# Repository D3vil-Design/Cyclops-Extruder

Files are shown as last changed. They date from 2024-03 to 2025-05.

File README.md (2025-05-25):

# Cyclops_Extruder ( Discontinued )

22nd september 2024 update:

Added 1.9.1 body , and tensioner arm for better print 
also added extra spacer that help in some cases where the gear are not tight fit and slides around 
Special thanks to "intensivecarebear80" ( discord User ) for the help in refining the designs and introducing the PTFE holder.

----------

The D3vil Designs "Cyclops" extruder was specifically engineered to address issues
associated with the stock Creality K1 / K1 Max extruder. Not only is the Cyclops a seamless
direct drop-in upgrade, but it also draws on proven technology from the Orbiter 2 project.
This integration enables the Cyclops to inherit superior functionality and performance
improvements, including but not limited to:
- Retraction speeds up to 120 mm/s
- Acceleration up to 3000 mm/s^2
- A powerful LDO Motor
- Large precise drive wheels for increased filament grip
- Improved and direct filament path to meet your needs (PLA, PETG, ASA, ABS, TPU, etc.)
This document serves as a reference guide. For optimal results, users must exercise care
and attentiveness during the assembly and installation processes. Neglecting to adhere
to the provided instructions may lead to suboptimal performance.
Note: This extruder requires root access to your printer.cfg in klipper.

Get full support at cuclops support channel on D3vil design discord 
Discord.gg/D3vil-Design

and feel free to join our Patreon for support, special offers , discounts and giveaways.
patreon.com/D3vilDesign

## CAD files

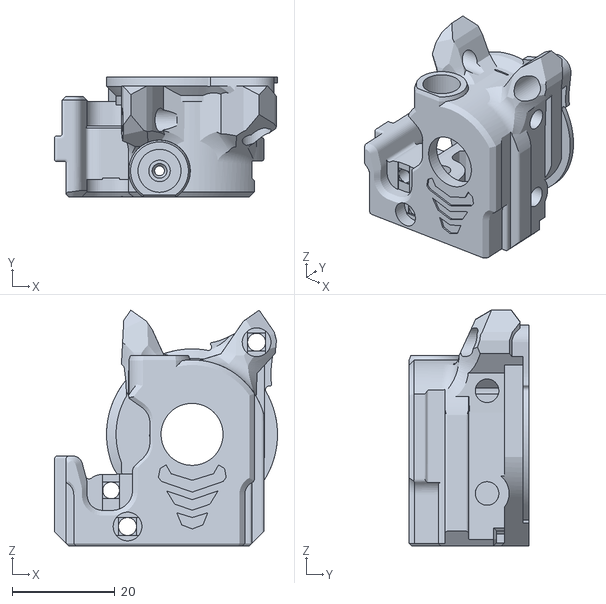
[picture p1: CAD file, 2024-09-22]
Models/Cyclops beta 1.9.1 Latest Sep24.stl
43.4 x 23.4 x 45.9

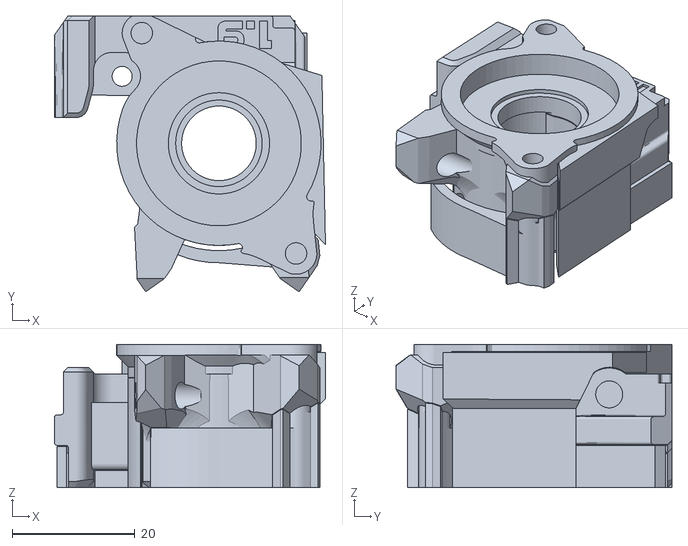
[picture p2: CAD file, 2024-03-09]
Models/PreSupported/Cyclops_v1.9_Supported.stl
44.1 x 44.9 x 23.4

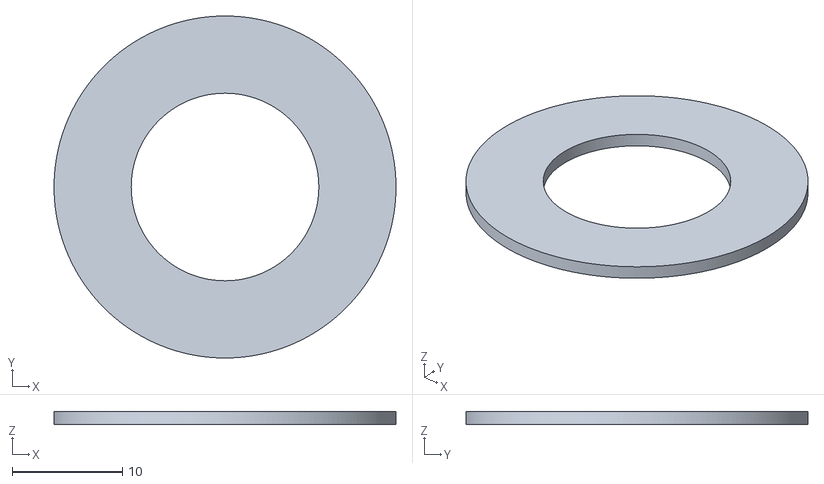
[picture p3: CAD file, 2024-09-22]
Models/Cyclops spacer Sep24.stl
31.0 x 31.0 x 1.20

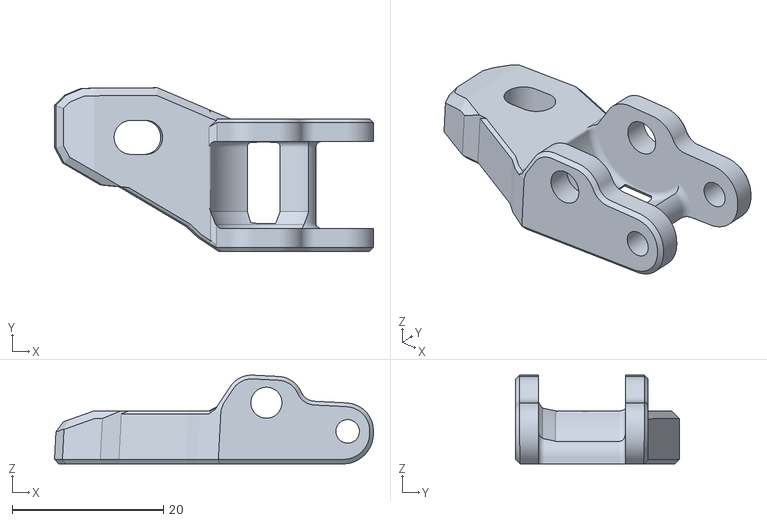
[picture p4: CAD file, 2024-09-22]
Models/Cyclops 1.9.1 Tensioner upgraded Sep24 (1).stl
42.2 x 21.6 x 11.7

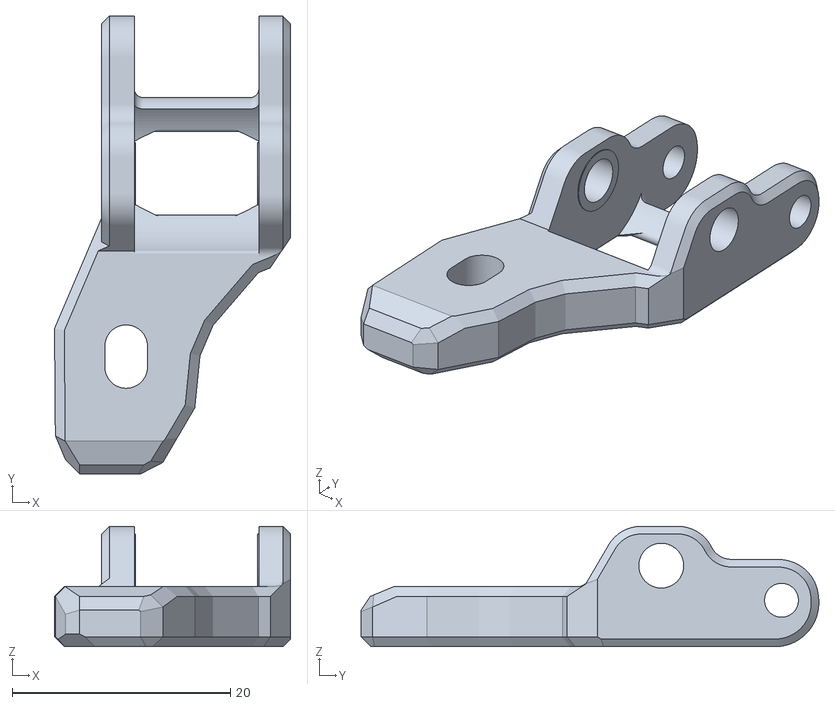
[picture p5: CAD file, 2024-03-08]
Models/Cyclops_Tensioner_1.9.stl
21.6 x 41.9 x 11.0

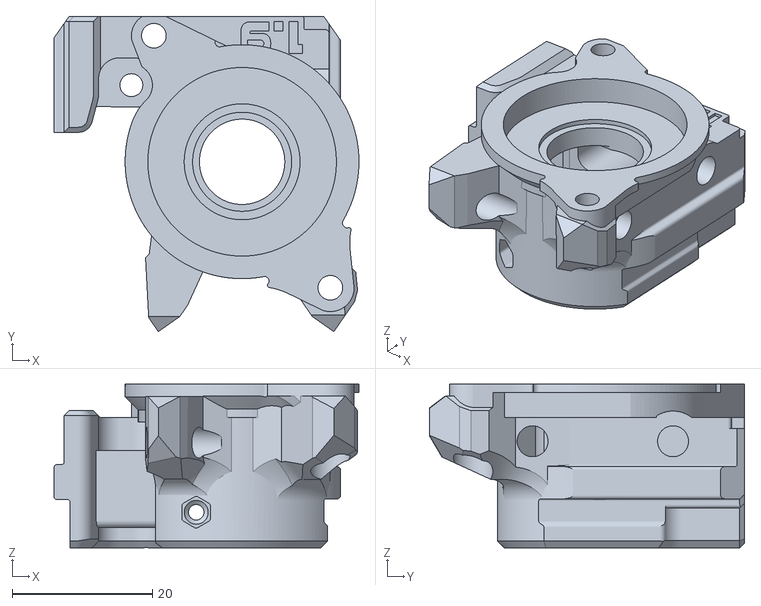
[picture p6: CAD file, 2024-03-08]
Models/Cyclops_Body_1.9.stl
43.4 x 44.9 x 23.3

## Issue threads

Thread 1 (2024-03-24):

Errors in the manual Guide/Cyclops Manual v1.5.pdf

NAPCAL, 2024-03-24:
Page 3
MR128 bearing (ID 8.0mm x OD 12.0mm x **3.5mm**)
The kit provides an MR128 bearing (ID 8.0mm, OD 12.0mm x **2.5mm**).
You can find both types, but most **2.5mm** versions will be open without shielding.

Pages 16-18
These show a drive gear with a grub/set screw hole, but the one provided in the kit is a type with no grub/set screw hole; this may confuse some builders.

DerrickDarrell, 2024-03-24:
We'll look into this, thanks

epicteammate, 2024-04-04:
To add to this post, perhaps this is just limited to myself:

Page 29
The "!" was not necessary for my printer, it caused everything to go backwards when I tested it loading/unloading and extruding/retracting. I haven't fully assembled it yet cause my PTFE tubing got lost in transit but that was my testing while hooked up and running the commands via Guppy screen.

mfraser, 2024-10-05:
Page 26. The PTFE tube is not required if you already have or are planning on using the Unicorn extruder.

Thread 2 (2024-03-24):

K1 wipe cycle; back of motor hits the back of the printer.

NAPCAL, 2024-03-24:
During the wipe cycle, the motor hits the back of the frame and rubs across while wiping.
This doesn't happen during bed mesh or bed probing.

DerrickDarrell, 2024-03-24:
Check the config changes in the manual. Page 31

NAPCAL, 2024-03-24:
Made those changes.

NAPCAL, 2024-03-24:
Settings when this happens.
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

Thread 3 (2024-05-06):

Filament sensor

KlausStoertebeker, 2024-05-06:
Hello,
it would be very nice to add a filament sensor to the Cyclops-Extruder housing, using the mechanics ans electronics of the "[Orbital V2.0 Filament Sensor](https://www.orbiterprojects.com/orbiter-filament-sensor/)" or the "[Prusa IR Filament Sensor](https://www.prusa3d.com/en/product/ir-filament-sensor/)".
Regards
"Klaus"

mfraser, 2024-10-05:
Henlor's filament runout sensor would be even better [K1 Extruder Filament Runout Sensor](https://www.printables.com/model/651002-k1-extruder-filament-runout-sensor)

LifeBlast, 2025-01-12:
Just here to bump this request.
This would be a really nice option.

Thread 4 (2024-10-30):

No bowden connection on 1.9.1

DasherDarren, 2024-10-30:
I was just wondering how I'm supposed to attach a bowden tube to the top on 1.9.1. I bought a kit and everything is assembled, but there is nothing that would help with the PTFE connection up top. Am I missing something? Thanks!

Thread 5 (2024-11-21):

Extruder runs wrong direction

Hamstershoes, 2024-11-21:
I just finished installing my Cyclops extruder and have my K1 max rooted with mainsail. some reason when i try to extrude the motor is retracting instead. has anyone experienced this? I found online that the motor could be plugged in the wrong way, but the plug is keyed and cant be plugged in wrong.

Hamstershoes, 2024-11-21:
Was provided the solution via FB and I wanted to share in case someone else has the same problem

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

downace, 2024-11-22:
This change is mentioned in the manual, page 29:

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

Hamstershoes, 2024-11-22:
> This change is mentioned in the manual (https://www.printables.com/model/797883-cyclops-extruder/files), page 29:
>
> ![image](https://private-user-images.githubusercontent.com/7350510/388737440-2b1fd82f-c680-4324-9d08-847561fc6d94.png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)

Sorry, I misspoke. Yes, the manual does instruct you to add the "!" in that line. However, it was after making that change that I had the issue. By removing the "!" that was added the problem was corrected.

downace, 2024-11-22:
> but the plug is keyed and cant be plugged in wrong

Maybe the connector was initially crimped in wrong way :thinking:.
Swapping any two wires will change the direction, AFAIK. But changing direction via config is ok too :+1:

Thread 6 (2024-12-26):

Cyclops Extruders are No Longer Available

robotwizard, 2024-12-26:
The Cyclops Extruders are No Longer Available, does this mean this project is dead?

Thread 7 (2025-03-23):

Bought Orbiter 2.5 and printed, but can't get it working

GHinkle423, 2025-03-23:
I purchased an Orbiter 2.5 and put it together with a body I printed got and printed from Printables, then assembled everything using the directions.  However, the wiring harness from the LDO was totally different colors and with a different plug than my K1 Max.  After looking around and asking on Reddit, I used the wiring instructions from the Libra, but now I get the following errors:

18:45:59 !! {"code":"key569","msg":"TMC 'extruder' reports error: DRV_STATUS: 001d0090 s2vsa=1(LowSideShort_A!) olb=1(OpenLoad_B!) cs_actual=29"}
18:45:59 !! {"code":"key569","msg":"TMC 'extruder' reports error: DRV_STATUS: 001d0090 s2vsa=1(LowSideShort_A!) olb=1(OpenLoad_B!) cs_actual=29"}
18:45:59 !! {"code":"key569","msg":"TMC 'extruder' reports error: DRV_STATUS: 001d0090 s2vsa=1(LowSideShort_A!) olb=1(OpenLoad_B!) cs_actual=29"}
18:45:59 !! {"code":"key569","msg":"TMC 'extruder' reports error: DRV_STATUS: 001d0090 s2vsa=1(LowSideShort_A!) olb=1(OpenLoad_B!) cs_actual=29"}

I believe that error means that each of the 4 cable is not connecting properly, and it crashes out the klipper.

I currently have the red LDO to the Black Creality wire in the plug, then blue into blue, yellow into orange, and green into red.

I don't have a multimeter to check continuity, but I can get ahold of one if I need it.

Any suggestions?

downace, 2025-03-24:
Looks like there is a short circuit between some of the wires...

The order of the wires should not produce errors, wrong order will only affect the rotation direction.

So you should check that none of the four wires are touching each other.

You should be able to find the issue visually, but a multimeter will make it easier

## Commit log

2024-03-08 Add STL files
    [Cyclops_Body_1.9.stl, Cyclops_Tensioner_1.9.stl]
2024-03-08 add presupported model from @tlace17
    [Cyclops_v1.9_Supported.stl]
2024-03-08 face down model.
    [Cyclops_v1.9._Supported.stl]
2024-03-09 updated for better interface
    [Cyclops_v1.9._Supported.stl, Cyclops_v1.9_Supported.stl]
2024-09-22 Add files via upload
    The latest model with better tolerances , PTFE tube holder , stronger tensioner arm , and a spacer for those having issues with gears moving !
    [Cyclops 1.9.1 Tensioner upgraded Sep24 (1).stl, Cyclops beta 1.9.1 Latest Sep24.stl, Cyclops spacer Sep24.stl]
